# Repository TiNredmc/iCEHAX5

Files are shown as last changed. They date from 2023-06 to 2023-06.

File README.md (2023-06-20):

# iCEHAX5 FPGA 

iCEHAX5 FPGA is a bare-minimum and open-source FPGA development board based on iCE5LP1K, iCE5LP2K, or iCE5LP4K. With the help of the iCEBlaster. Drag-and-Drop programming made it easy. Compatible with Windows, Mac OS and Linux without any additional drivers. 

# iCEHAX5 Hardware Specifications 
- iCE5LP1K or iCE5LP2K or iCE5LP4K (QFN48 package; -SG48).
    - 1100 or 2048 or 3520 Programmable Logic Cells (PLBs).
    - 64 or 80 or 80 kBit Block RAM (BRAM). 
    - Single programmable Phase Lock Loop (PLL).
    - 2 or 4 or 4 Multiplier And Accumulator DSP blocks (MAC).
    - 1 or 2 or 2 I2C Hard IPs.
    - 1 or 2 or 2 SPI Hard IPs.
    - 10Khz and 48MHz internal Oscillator 
- 37 Usable Pins
    - 34 User accessible PIOs
    - 3 Open Drain Only pins for RGB LED.
- iCEBlaster USB Drag and Drop programmer.
    - Based on STM32F042F4P6 or STM32F042F6P6.
    - Bitstream storage : BR24G1MFJ 128kByte I2C EEPROM (I know it sucks, but it work!).
    - Bitstream transfer to the FPGA over SPI bus 
- On board LED status for iCEBlaster.



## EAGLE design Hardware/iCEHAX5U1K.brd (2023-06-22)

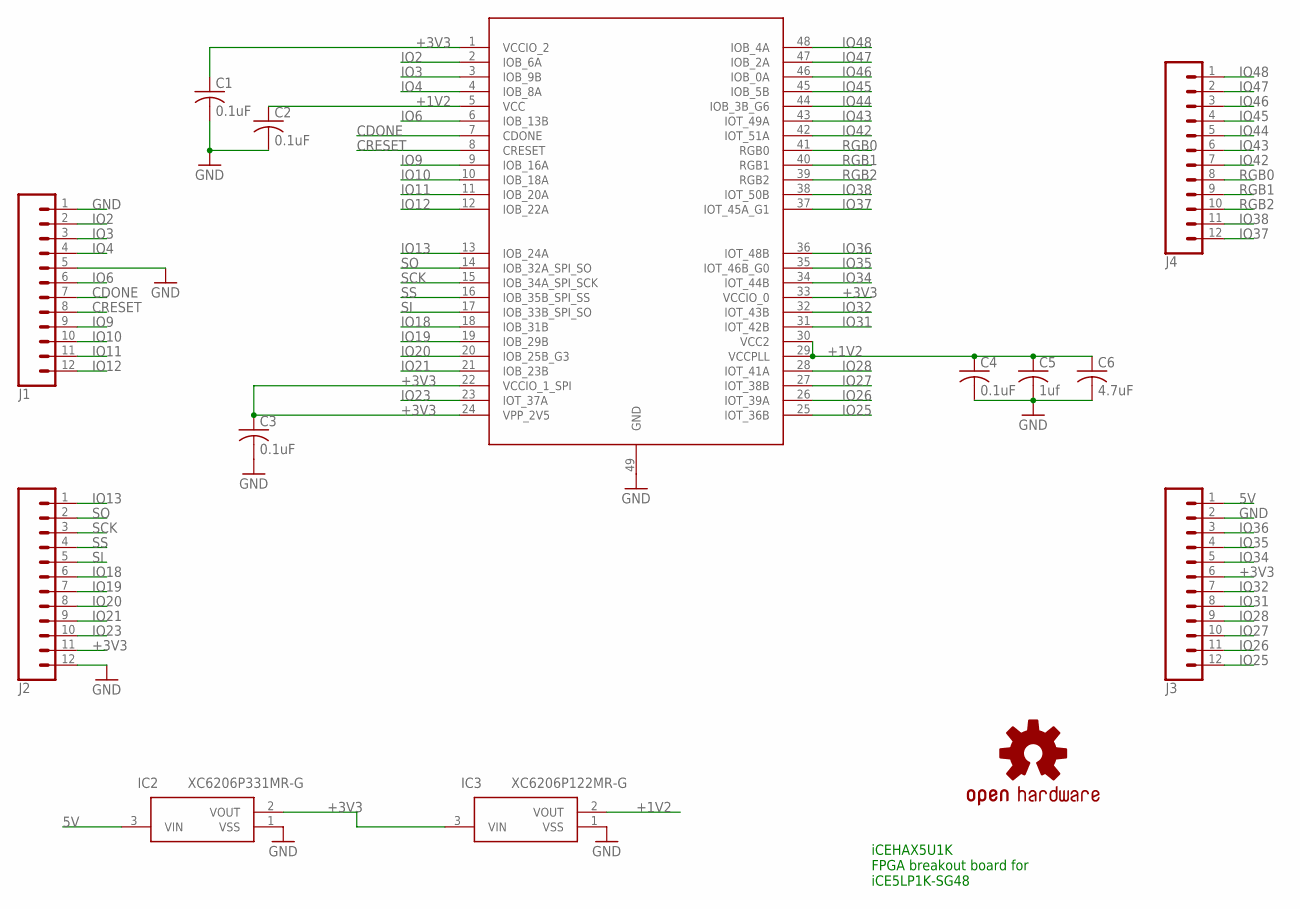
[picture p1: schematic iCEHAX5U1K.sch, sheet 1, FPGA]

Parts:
C1, C2, C3, C4: 0.1uF; C0603
C5: 1uf; C0603
C6: 4.7uF; C0603
IC1: ICE5LP1K-SG48; QFN50P700X700X100-48T535N
IC2: XC6206P331MR-G; SOT95P280X130-3N
IC3: XC6206P122MR-G; SOT95P280X130-3N
J1, J2, J3, J4: CONN_12NO_SILK; 1X12_NO_SILK
LOGO1: OSHW-LOGOMINI; OSHW-LOGO-MINI

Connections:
5V: IC2.3 (VIN), J3.1; also elsewhere on the board
+1V2: C2.1, C4.1, C5.1, C6.1, IC1.5 (VCC), IC1.29 (VCCPLL), IC1.30 (VCC2), IC3.2 (VOUT)
+3V3: C1.1, C3.1, IC1.1 (VCCIO_2), IC1.22 (VCCIO_1_SPI), IC1.24 (VPP_2V5), IC1.33 (VCCIO_0), IC2.2 (VOUT), IC3.3 (VIN), J2.11, J3.6; also elsewhere on the board
CDONE: IC1.7 (CDONE), J1.7
CRESET: IC1.8 (CRESET), J1.8; also elsewhere on the board
GND: C1.2, C2.2, C3.2, C4.2, C5.2, C6.2, IC1.49 (GND), IC2.1 (VSS), IC3.1 (VSS), J1.1, J1.5, J2.12, J3.2; also elsewhere on the board
IO2: IC1.2 (IOB_6A), J1.2
IO3: IC1.3 (IOB_9B), J1.3
IO4: IC1.4 (IOB_8A), J1.4
IO6: IC1.6 (IOB_13B), J1.6
IO9: IC1.9 (IOB_16A), J1.9
IO10: IC1.10 (IOB_18A), J1.10
IO11: IC1.11 (IOB_20A), J1.11
IO12: IC1.12 (IOB_22A), J1.12
IO13: IC1.13 (IOB_24A), J2.1
IO18: IC1.18 (IOB_31B), J2.6
IO19: IC1.19 (IOB_29B), J2.7
IO20: IC1.20 (IOB_25B_G3), J2.8
IO21: IC1.21 (IOB_23B), J2.9
IO23: IC1.23 (IOT_37A), J2.10
IO25: IC1.25 (IOT_36B), J3.12
IO26: IC1.26 (IOT_39A), J3.11
IO27: IC1.27 (IOT_38B), J3.10
IO28: IC1.28 (IOT_41A), J3.9
IO31: IC1.31 (IOT_42B), J3.8
IO32: IC1.32 (IOT_43B), J3.7
IO34: IC1.34 (IOT_44B), J3.5
IO35: IC1.35 (IOT_46B_G0), J3.4
IO36: IC1.36 (IOT_48B), J3.3
IO37: IC1.37 (IOT_45A_G1), J4.12
IO38: IC1.38 (IOT_50B), J4.11
IO42: IC1.42 (IOT_51A), J4.7
IO43: IC1.43 (IOT_49A), J4.6
IO44: IC1.44 (IOB_3B_G6), J4.5
IO45: IC1.45 (IOB_5B), J4.4
IO46: IC1.46 (IOB_0A), J4.3
IO47: IC1.47 (IOB_2A), J4.2
IO48: IC1.48 (IOB_4A), J4.1
RGB0: IC1.41 (RGB0), J4.8
RGB1: IC1.40 (RGB1), J4.9
RGB2: IC1.39 (RGB2), J4.10
SCK: IC1.15 (IOB_34A_SPI_SCK), J2.3; also elsewhere on the board
SI: IC1.17 (IOB_33B_SPI_SO), J2.5; also elsewhere on the board
SO: IC1.14 (IOB_32A_SPI_SO), J2.2; also elsewhere on the board
SS: IC1.16 (IOB_35B_SPI_SS), J2.4; also elsewhere on the board

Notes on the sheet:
iCEHAX5U1K FPGA breakout board for iCE5LP1K-SG48

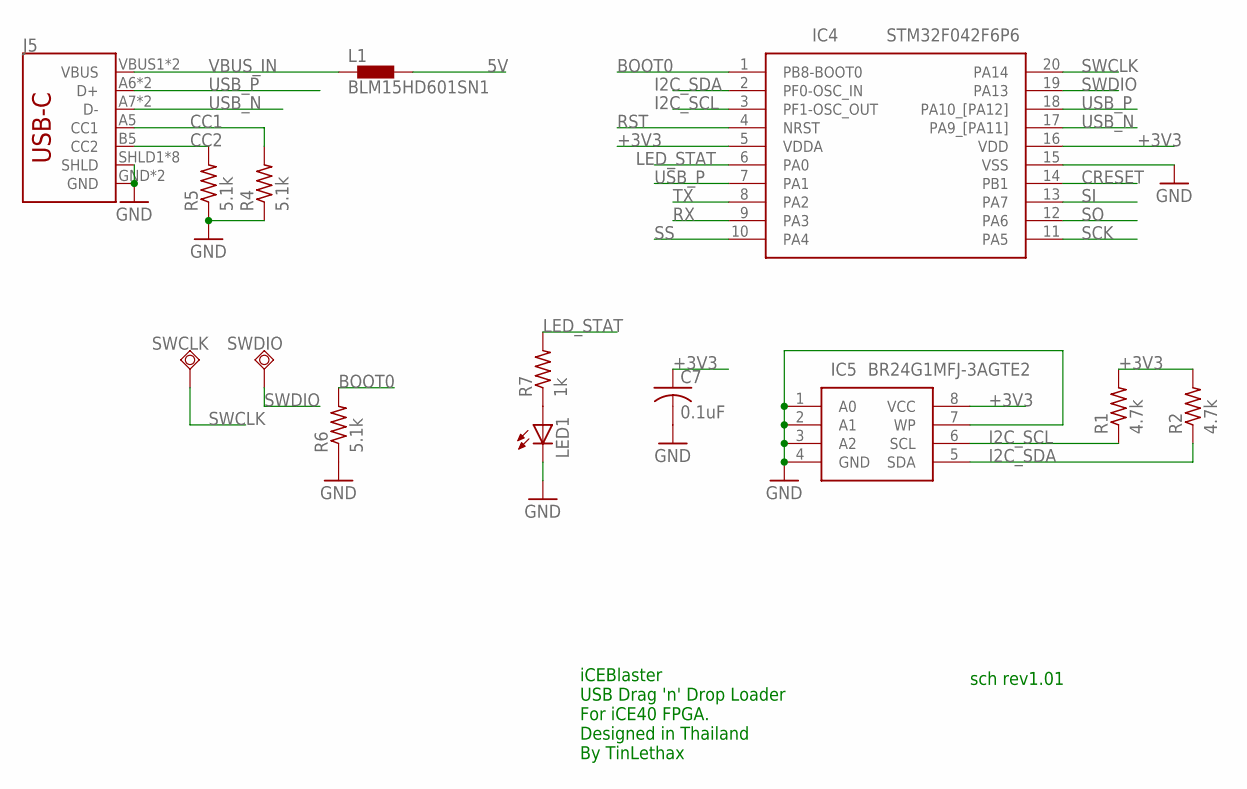
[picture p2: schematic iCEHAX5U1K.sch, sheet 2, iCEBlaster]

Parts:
C7: 0.1uF; C0603
IC4: STM32F042F6P6; SOP65P640X120-20N
IC5: BR24G1MFJ-3AGTE2; SOP126P620X150-8N
J5: SPARKFUN-CONNECTORS_USB_C16PIN; SPARKFUN-CONNECTORS_USB-C-16P
L1: BLM15HD601SN1; 0402
LED1: LEDCHIP-LED0603; CHIP-LED0603
R1, R2: 4.7k; R0603
R4, R5, R6: 5.1k; R0603
R7: 1k; R0603
SWCLK: TPSQTP15SQ; TP15SQ
SWDIO: TPSQTP15SQ; TP15SQ

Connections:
5V: L1.2; also elsewhere on the board
+3V3: C7.1, IC4.5 (VDDA), IC4.16 (VDD), IC5.8 (VCC), R1.2, R2.2; also elsewhere on the board
BOOT0: IC4.1 (PB8-BOOT0), R6.2
CC1: J5.A5 (CC1), R4.2
CC2: J5.B5 (CC2), R5.2
CRESET: IC4.14 (PB1); also elsewhere on the board
GND: C7.2, IC4.15 (VSS), IC5.1 (A0), IC5.2 (A1), IC5.3 (A2), IC5.4 (GND), IC5.7 (WP), J5.GND, J5.GND2 (GND), J5.SHLD1 (SHLD), J5.SHLD2 (SHLD), J5.SHLD3 (SHLD), J5.SHLD4 (SHLD), J5.SHLD5 (SHLD), J5.SHLD6 (SHLD), J5.SHLD7 (SHLD), J5.SHLD8 (SHLD), LED1.C, R4.1, R5.1, R6.1; also elsewhere on the board
I2C_SCL: IC4.3 (PF1-OSC_OUT), IC5.6 (SCL), R1.1
I2C_SDA: IC4.2 (PF0-OSC_IN), IC5.5 (SDA), R2.1
LED: LED1.A, R7.1
LED_STAT: IC4.6 (PA0), R7.2
RST: IC4.4 (NRST)
RX: IC4.9 (PA3)
SCK: IC4.11 (PA5); also elsewhere on the board
SI: IC4.13 (PA7); also elsewhere on the board
SO: IC4.12 (PA6); also elsewhere on the board
SS: IC4.10 (PA4); also elsewhere on the board
SWCLK: IC4.20 (PA14), SWCLK.TP
SWDIO: IC4.19 (PA13), SWDIO.TP
TX: IC4.8 (PA2)
USB_N: IC4.17 (PA9_[PA11]), J5.A7 (D-), J5.B7 (D-)
USB_P: IC4.7 (PA1), IC4.18 (PA10_[PA12]), J5.A6 (D+), J5.B6 (D+)
VBUS_IN: J5.VBUS1 (VBUS), J5.VBUS2 (VBUS), L1.1

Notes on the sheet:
iCEBlaster USB Drag 'n' Drop Loader For iCE40 FPGA. Designed in Thailand By TinLethax
sch rev1.01

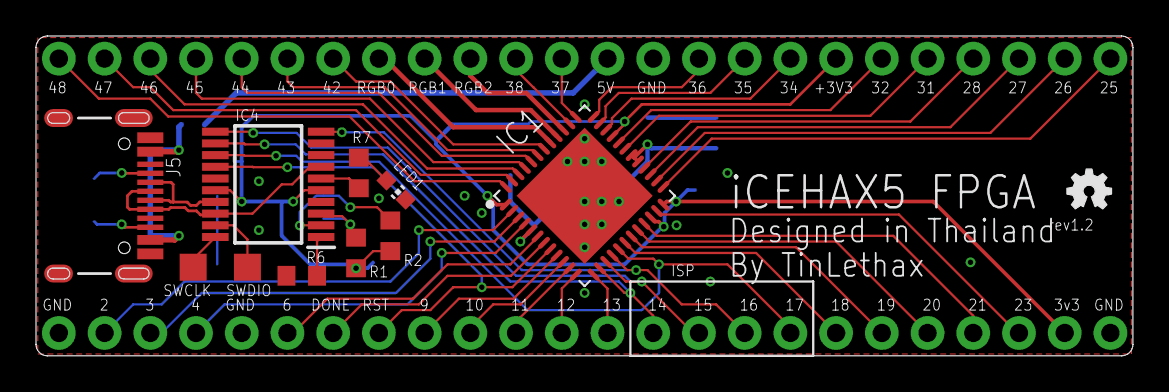
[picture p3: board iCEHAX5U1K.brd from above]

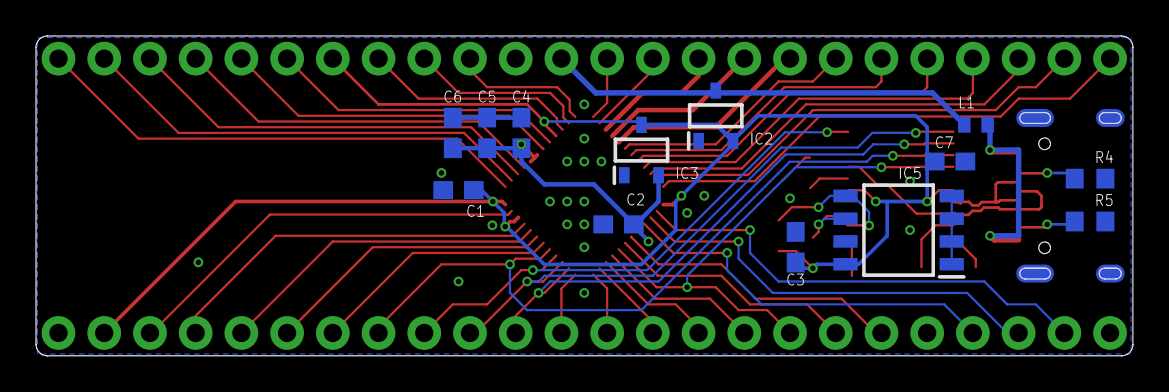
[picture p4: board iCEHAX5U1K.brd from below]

Board: 2 copper layers, 60.9 x 17.8 mm, 28 parts (13 on the bottom side), 57 nets.

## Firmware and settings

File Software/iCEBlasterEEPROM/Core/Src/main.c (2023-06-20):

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
/* Includes ------------------------------------------------------------------*/
#include "main.h"
#include "usb_device.h"

/* USER CODE BEGIN Includes */
#include <stdint.h>
/* USER CODE END Includes */

I2C_HandleTypeDef hi2c1;

SPI_HandleTypeDef hspi1;

/* USER CODE BEGIN PV */
uint8_t reset_flag;
uint8_t eeprom_buf[255];
uint8_t eeprom_dev_addr = EEPROM_ADDR; // ROHM BR24G1MF 128KBytes I2C EEPROM (Running at 400KHz).
uint32_t eeprom_addr = 0;

const uint8_t dummy[19] = {0};// dummy byte to kick start bit stream loading process.

/* USER CODE END PV */

void SystemClock_Config(void);
static void MX_GPIO_Init(void);
static void MX_I2C1_Init(void);
static void MX_SPI1_Init(void);
/* USER CODE BEGIN 0 */
void iCE40_flash(){
	uint16_t end_addr = 256;
	HAL_I2C_Mem_Read(&hi2c1, EEPROM_ADDR, 0, I2C_MEMADD_SIZE_16BIT, eeprom_buf, 256, HAL_MAX_DELAY);
		for(uint8_t i=0; i < 255; i++){// Looking for bitstream preamble on EEPROM. If found, send it to FPGA.
			if(*(eeprom_buf+i) == 0x7E){
				if(*(eeprom_buf+1+i) == 0xAA){
					if(*(eeprom_buf+2+i) == 0x99){
						if(*(eeprom_buf+3+i) == 0x7E){
							HAL_GPIO_WritePin(LED_STAT_GPIO_Port, LED_STAT_Pin, 1);// Turn Status LED on.
							goto flash;
						}
					}
				}
			}
		}

		goto ret;

		flash:
		// LED status off
		HAL_GPIO_WritePin(LED_STAT_GPIO_Port, LED_STAT_Pin, GPIO_PIN_RESET);

		/* This part is reset sequence of iCE40 FPGA
		 * CE low
		 * CRESET low
		 * delay 2ms
		 * CRESET high
		 * delay 200ms
		 * SPI TX
		 */

		HAL_GPIO_WritePin(SPI1_CE_GPIO_Port, SPI1_CE_Pin, GPIO_PIN_RESET);
		HAL_GPIO_WritePin(CRESET_GPIO_Port, CRESET_Pin, GPIO_PIN_RESET);
		HAL_Delay(2);
		HAL_GPIO_WritePin(CRESET_GPIO_Port, CRESET_Pin, GPIO_PIN_SET);
		HAL_Delay(250);

		do{
			HAL_GPIO_TogglePin(LED_STAT_GPIO_Port, LED_STAT_Pin);
			HAL_I2C_Mem_Read(&hi2c1, eeprom_dev_addr, (uint16_t)eeprom_addr, I2C_MEMADD_SIZE_16BIT, eeprom_buf, 256, HAL_MAX_DELAY);
			for(uint16_t i=0; i < 256; i++){// Looking for bitstream endding on EEPROM.
				if(*(eeprom_buf+i) == 0x01){
					if(*(eeprom_buf+1+i) == 0x06){
						if(*(eeprom_buf+2+i) == 0x00){
							end_addr = i+3;
						}
					}
				}
			}
			HAL_SPI_Transmit(&hspi1, eeprom_buf, end_addr, HAL_MAX_DELAY);// SPI TX
			eeprom_addr += 256;
			if(eeprom_addr > 65535)
					eeprom_dev_addr = 0xA2;
		}while(end_addr == 256);
		eeprom_dev_addr = EEPROM_ADDR;
		eeprom_addr = 0;
		HAL_SPI_Transmit(&hspi1, dummy, 19, HAL_MAX_DELAY);// Send dummy bytes to kickstart iCE40
		HAL_GPIO_WritePin(SPI1_CE_GPIO_Port, SPI1_CE_Pin, GPIO_PIN_SET);

		ret:
		return;

}
/* USER CODE END 0 */

/**
  * @brief  The application entry point.
  * @retval int
  */
int main(void)
{
  /* MCU Configuration--------------------------------------------------------*/

  /* Reset of all peripherals, Initializes the Flash interface and the Systick. */
  HAL_Init();

  /* Configure the system clock */
  SystemClock_Config();

  /* Initialize all configured peripherals */
  MX_GPIO_Init();
  MX_I2C1_Init();
  MX_SPI1_Init();
  MX_USB_DEVICE_Init();
  /* USER CODE BEGIN 2 */
  HAL_GPIO_WritePin(SPI1_CE_GPIO_Port, SPI1_CE_Pin, 1);// Release SPI CE.
  HAL_GPIO_WritePin(CRESET_GPIO_Port, CRESET_Pin, 1);// Release FPGA's CRESET.
  iCE40_flash();// iCE40 will start if there's bitstream on the EEPROM. LED will on if bitstream were found on the EEPROM
  HAL_GPIO_WritePin(USB_EN_GPIO_Port, USB_EN_Pin, 1);// Enable USB to enumerate USB. By release open drain output
  /* USER CODE END 2 */

  /* Infinite loop */
  /* USER CODE BEGIN WHILE */
  while (1)
  {
    /* USER CODE END WHILE */

    /* USER CODE BEGIN 3 */
	  if(reset_flag == 1){// if receive USB reset flag after Bitstream loaded.
		  iCE40_flash();// Upload bitstream to FPGA after USB transfered Bitstream to EEPROM.
		  // Auto USB reconnect.
		  HAL_Delay(200);
		  HAL_GPIO_WritePin(USB_EN_GPIO_Port, USB_EN_Pin, 0);
		  HAL_Delay(100);
		  HAL_GPIO_WritePin(USB_EN_GPIO_Port, USB_EN_Pin, 1);
		  reset_flag = 0;
	  }
  }
  /* USER CODE END 3 */
}

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


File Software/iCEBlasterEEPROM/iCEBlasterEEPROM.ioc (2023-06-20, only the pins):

Mcu.UserName=STM32F042F6Px
PA0.GPIO_Label=LED_STAT
PA0.Signal=GPIO_Output
PA1.GPIO_Label=USB_EN
PA1.Signal=GPIO_Output
PA11.Signal=USB_DM
PA12.Signal=USB_DP
PA13.Signal=SYS_SWDIO
PA14.Signal=SYS_SWCLK
PA4.GPIO_Label=SPI1_CE
PA4.Signal=GPIO_Output
PA5.Signal=SPI1_SCK
PA6.Signal=SPI1_MISO
PA7.Signal=SPI1_MOSI
PB1.GPIO_Label=CRESET
PB1.Signal=GPIO_Output
PF0-OSC_IN.Signal=I2C1_SDA
PF1-OSC_OUT.Signal=I2C1_SCL

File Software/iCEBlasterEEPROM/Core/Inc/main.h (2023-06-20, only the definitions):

#define EEPROM_ADDR 0xA0
#define LED_STAT_Pin GPIO_PIN_0
#define LED_STAT_GPIO_Port GPIOA
#define USB_EN_Pin GPIO_PIN_1
#define USB_EN_GPIO_Port GPIOA
#define SPI1_CE_Pin GPIO_PIN_4
#define SPI1_CE_GPIO_Port GPIOA
#define CRESET_Pin GPIO_PIN_1
#define CRESET_GPIO_Port GPIOB

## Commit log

2023-06-20 Added Board pic.
2023-06-22 Top PIO Bank design issue fixed. - Top PIO Bank (Pin 25 and up) was missing the VCC_IO rail due to confusion of pin 33.
    [iCEHAX5U1K.brd, iCEHAX5U1K.sch]

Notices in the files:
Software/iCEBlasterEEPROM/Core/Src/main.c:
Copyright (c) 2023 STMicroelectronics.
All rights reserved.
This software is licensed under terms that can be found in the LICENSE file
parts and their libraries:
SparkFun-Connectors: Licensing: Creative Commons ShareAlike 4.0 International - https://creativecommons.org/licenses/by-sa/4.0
